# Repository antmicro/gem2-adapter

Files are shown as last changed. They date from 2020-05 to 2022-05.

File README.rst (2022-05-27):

GEM2 Adapter
============

Copyright (c) 2020 `Antmicro <https://www.antmicro.com>`_


   
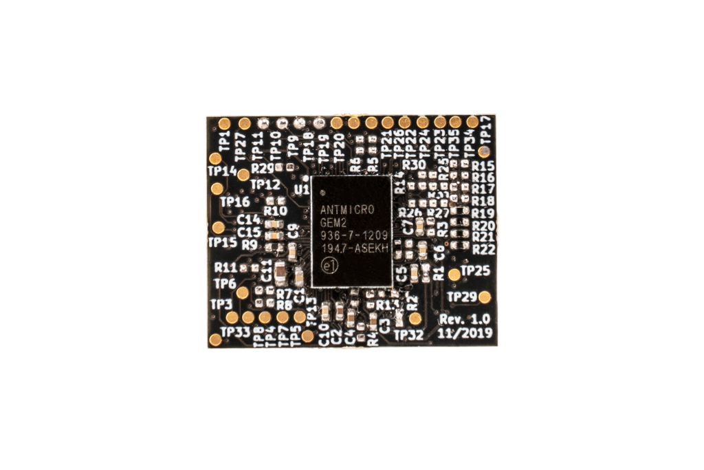
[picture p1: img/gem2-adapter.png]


This repository contains PCB design files for an adapter board accommodating the GEM2 chip created jointly by `zGlue <http://zglue.com>`_ and `Antmicro <http://www.antmicro.com>`_.
The `GEM2 design <https://zglue.com/design-automation/oci/project/gem2>`_ utilizes the zGlue ZiP chiplet technology and has been prepared using zGlue's `ChipBuilder <http://chipbuilder.zglue.com/>`_ tool.
The design has been produced as a single integrated circuit in the LGA-96 package.

The GEM2 chip contains the following components located on a dynamically reconfigurable interposer:

* PicoRV32-based "Raven" RISC-V ASIC implementation (see `raven-picorv32 <https://github.com/efabless/raven-picorv32>`_ and associated resources)
* Lattice ``ICE40UP5K-UWG30ITR`` FPGA image processing
* 32Mbit SPI FLASH memory
* 12MHz system clock generator 
* Internal LDOs and power management unit maintaining 1V2, 1V8, 2V5, 3V3 system supplies

The chip is supplied from a single ``VUSB`` voltage of 5 VDC.
The board break-routes signals for MIPI Interfaces (Input and Output) along with Flash and FPGA programming pins and power supplies.

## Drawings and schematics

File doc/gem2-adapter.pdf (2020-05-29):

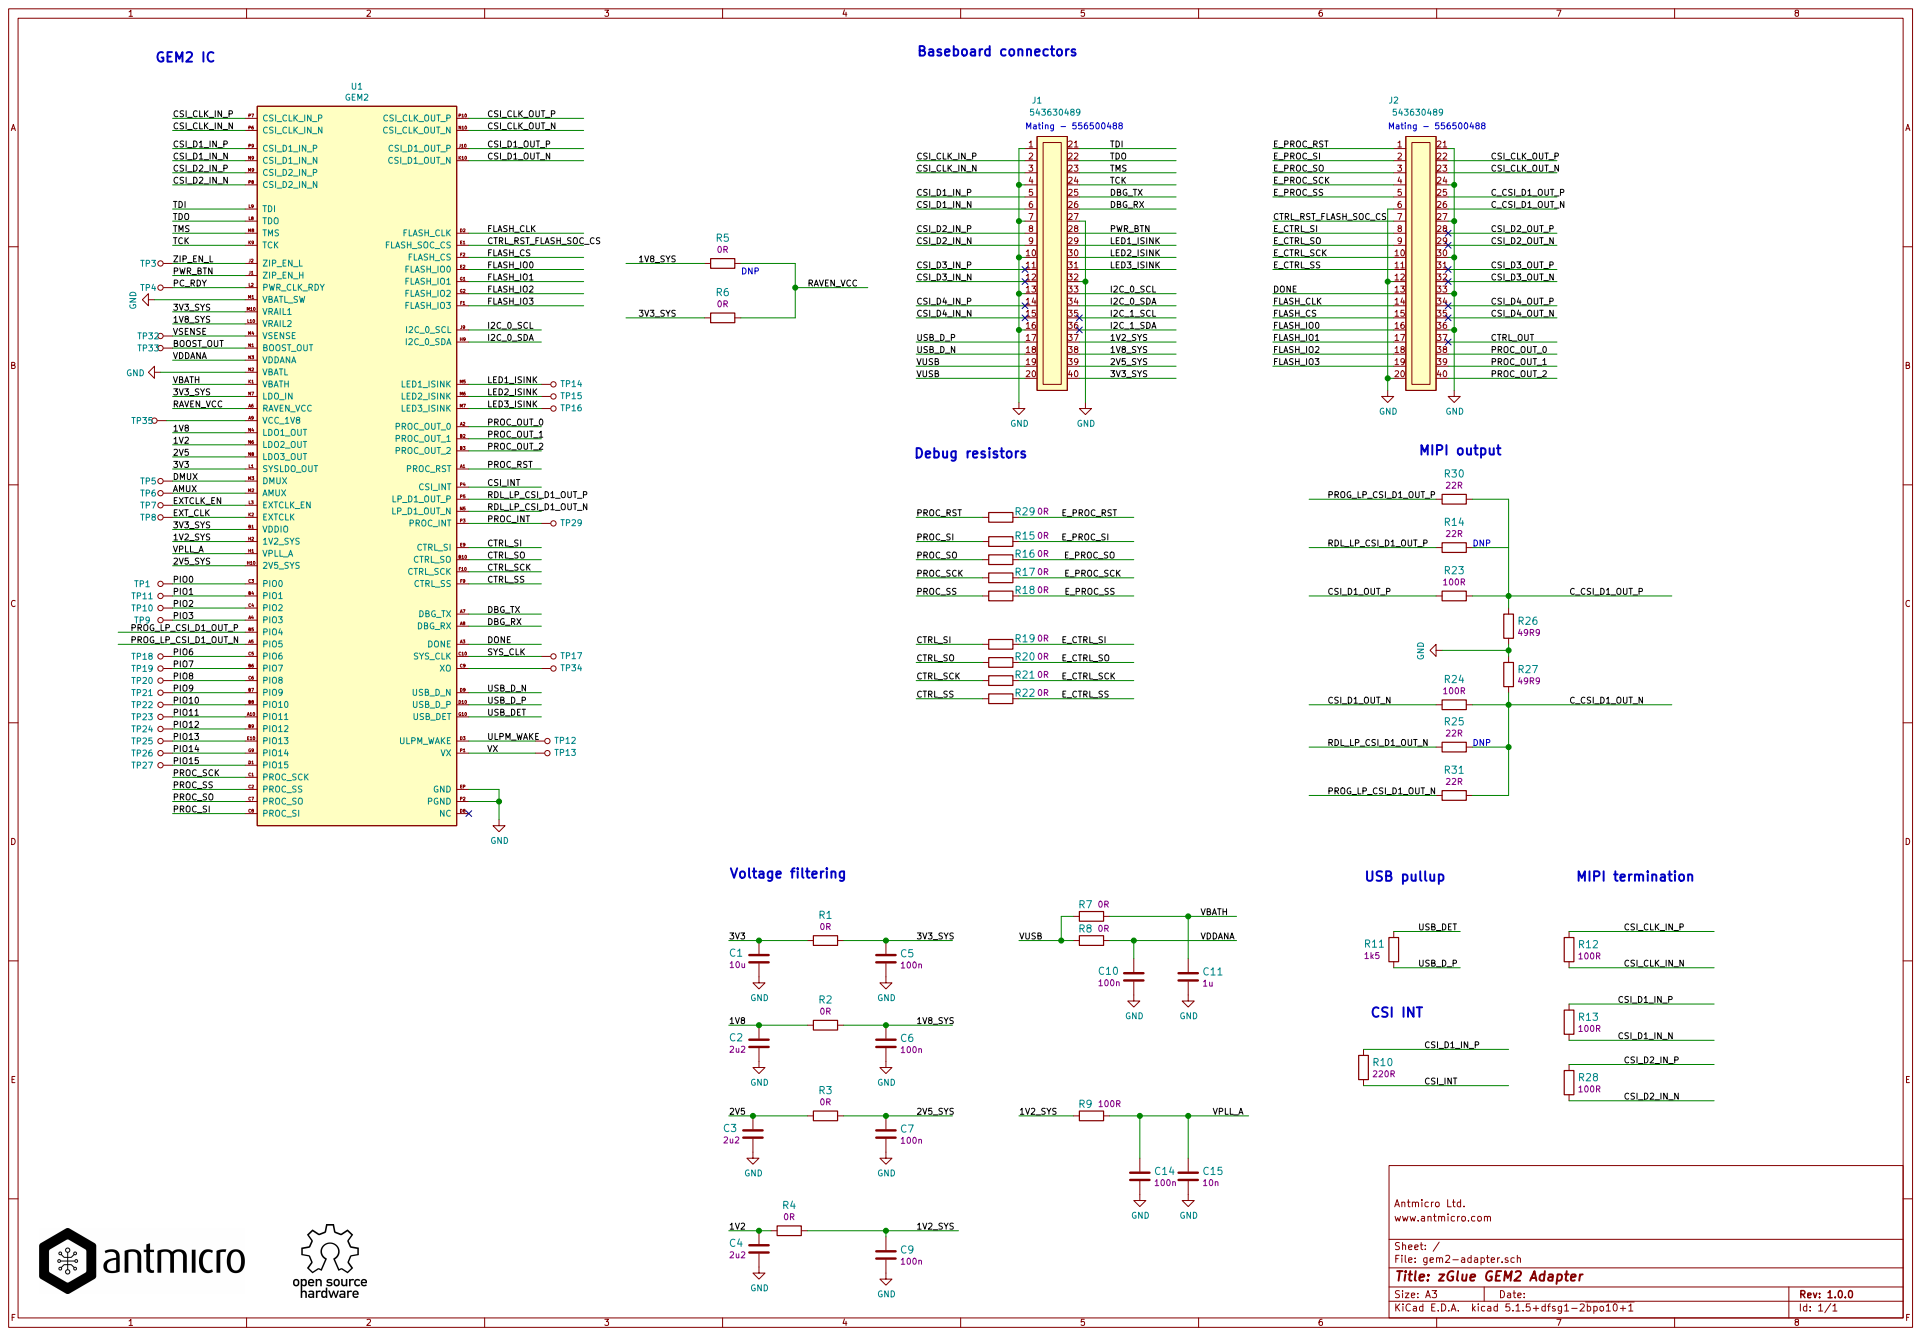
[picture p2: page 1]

Antmicro Ltd.
File: gem2-adapter.sch Sheet: / www.antmicro.com

Id: 1/1 Title: zGlue GEM2 Adapter

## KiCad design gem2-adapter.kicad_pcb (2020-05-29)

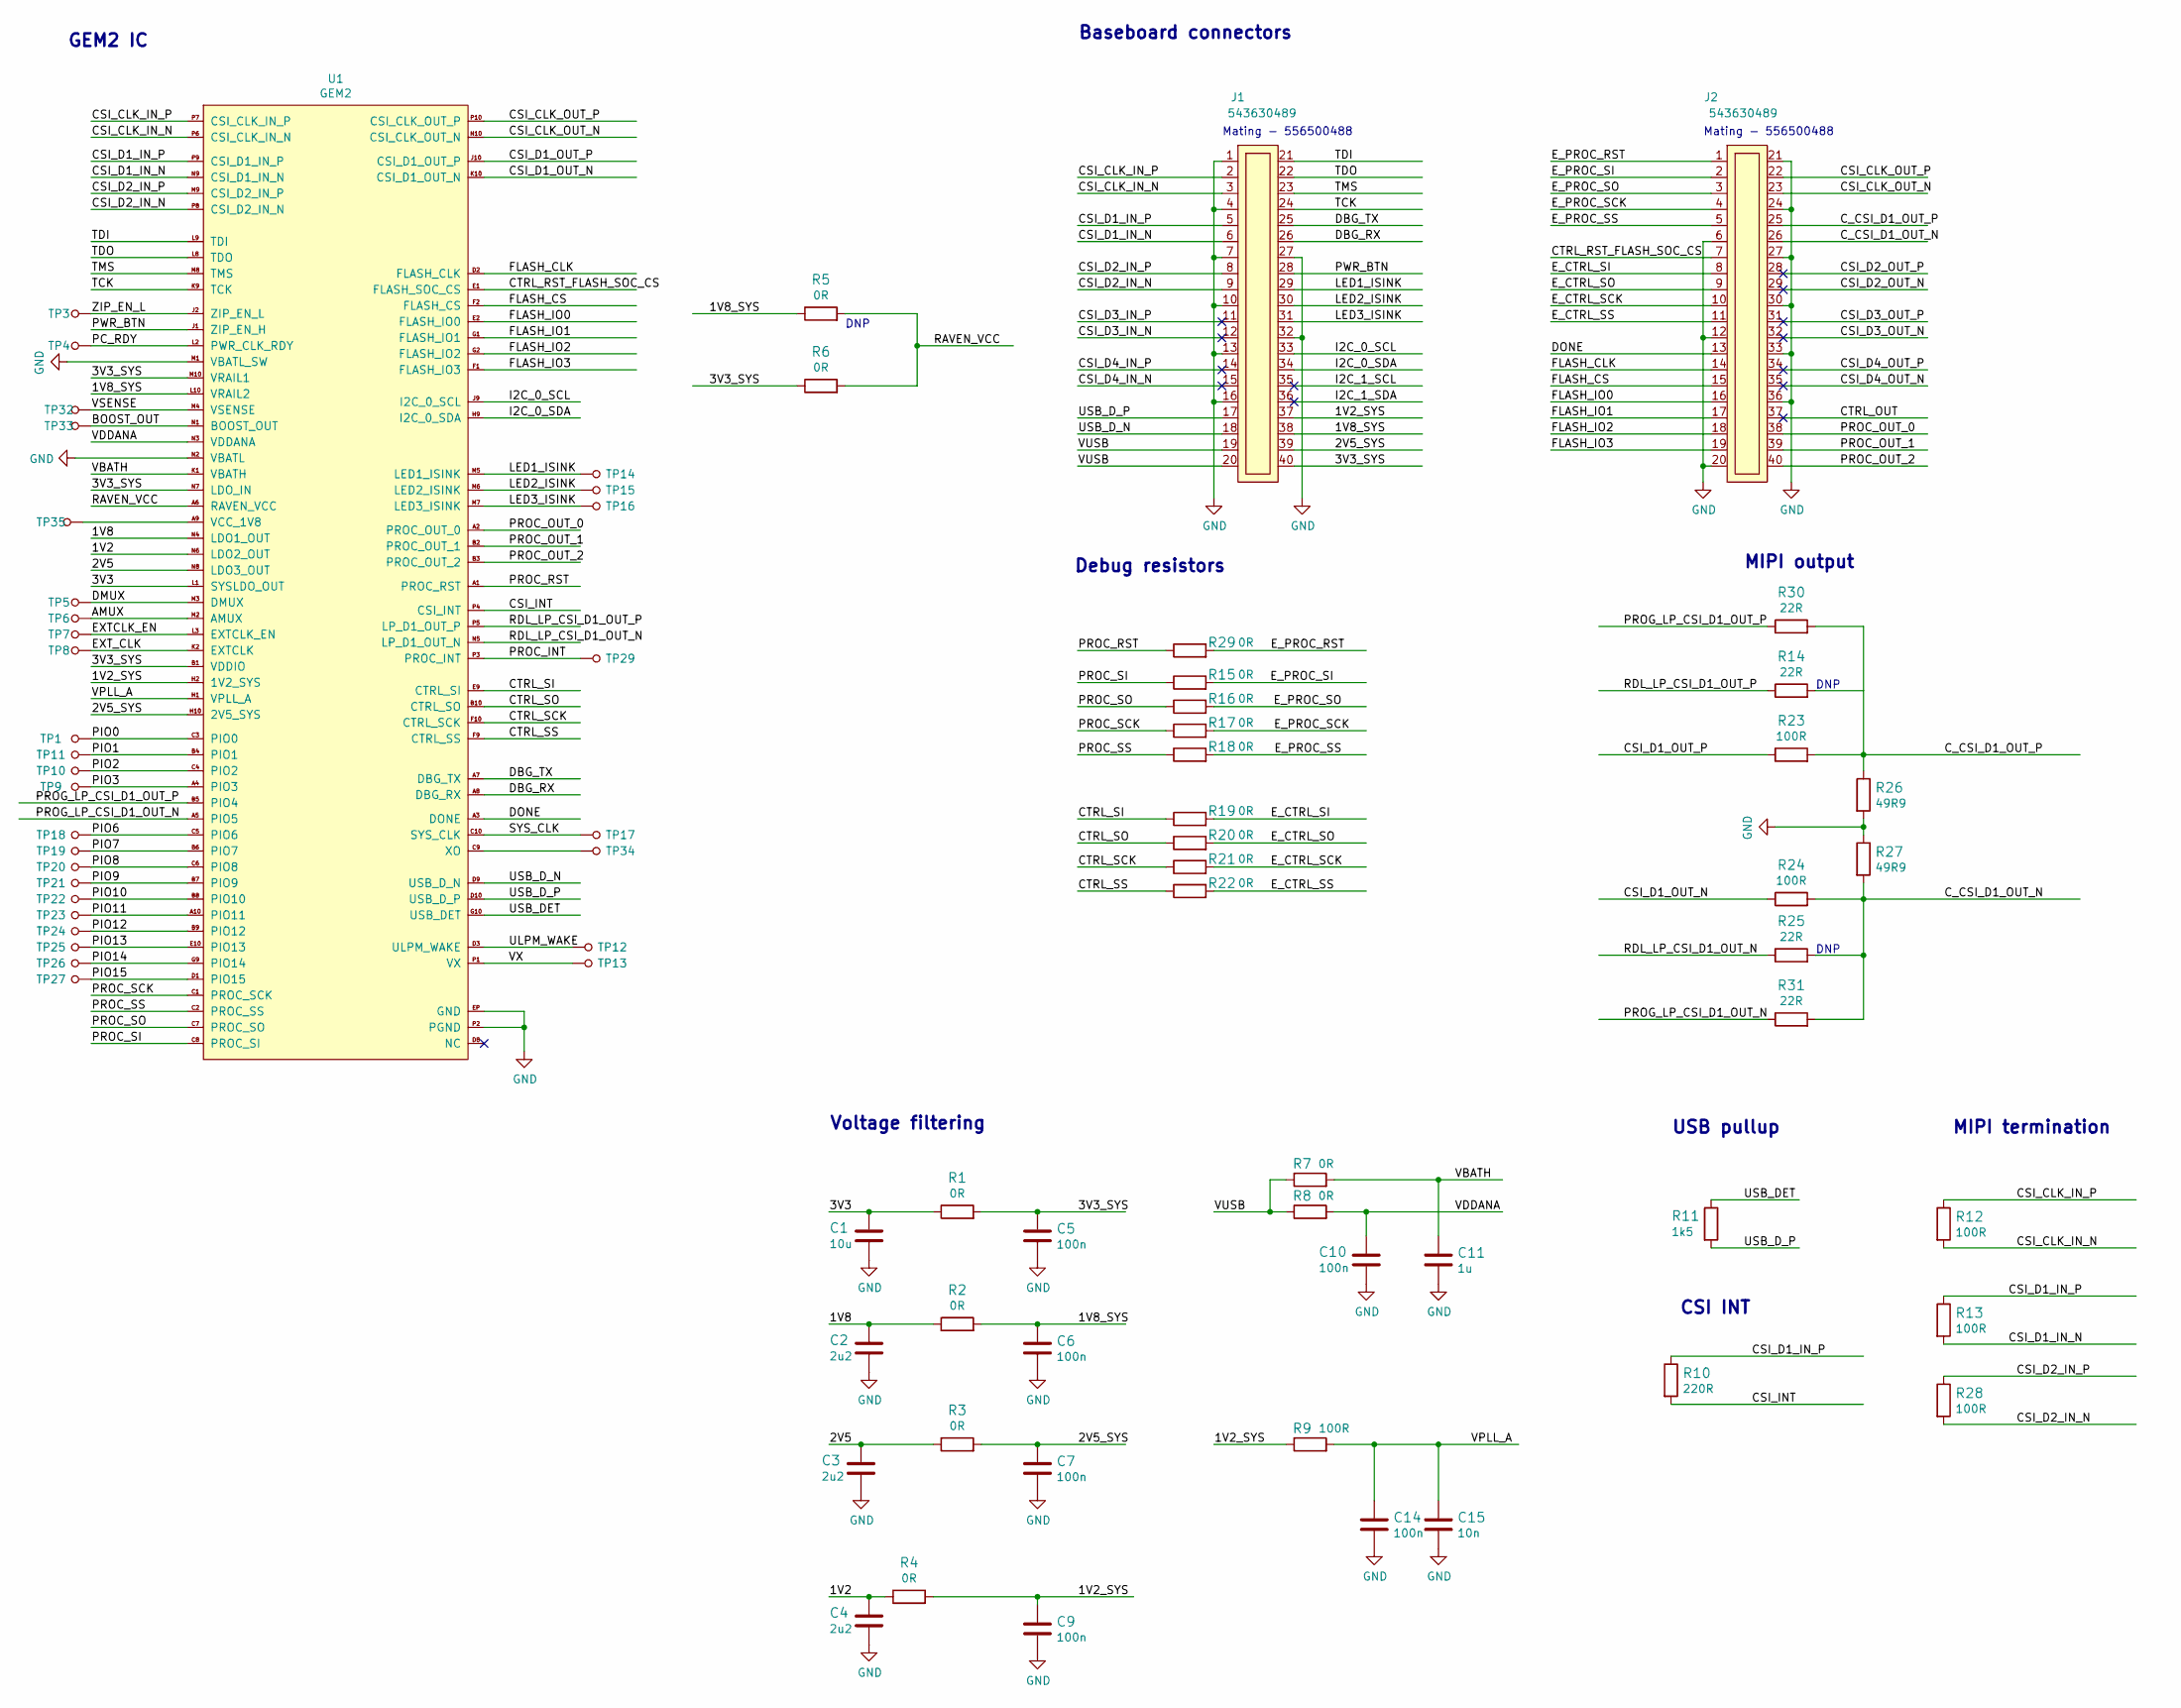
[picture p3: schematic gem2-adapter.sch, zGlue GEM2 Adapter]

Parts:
C1: C_10u_0402; 0402-cap; MPN C1005X5R0J106M050BC
C2, C3, C4: C_2u2_0402; 0402-cap; MPN C1005X5R1A225K050BC
C5, C6, C7, C9, C10, C14: C_100n_0402_6V3; 0402-cap; MPN 0402X104K6R3CT
C11: C_1u_0603; 0603-cap; MPN 0603X105K160CT
C15: C_10n_0402; 0402-cap; MPN 04025G103ZAT2A
J1, J2: 543630489; MPN 543630489
R1, R2, R3, R4, R5, R6, R7, R8, R15, R16, R17, R18, R19, R20, R21, R22, R29: R_0R_0402; 0402-res; MPN ERJ2GE0R00X
R9, R12, R13, R28: R_100R_0402; 0402-res; MPN CR0402-FX-1000GLF
R10: R_220R_0402; 0402-res; MPN CRG0402J220R
R11: R_1k5_0402; 0402-res; MPN ERJ2RKF1501X
R14, R25, R30, R31: R_22R_0402; 0402-res; MPN CRCW040222R0FKED
R23, R24: R_120R_0402; 0402-res; MPN CR0402-FX-1000GLF
R26, R27: R_49R9_0402; 0402-res; MPN CRCW040249R9FKED
TP1, TP3, TP4, TP5, TP6, TP7, TP8, TP9, TP10, TP11, TP12, TP13, TP14, TP15, TP16, TP17, TP18, TP19, TP20, TP21, TP22, TP23, TP24, TP25, TP26, TP27, TP29, TP32, TP33, TP34, TP35: TP_SMD1MM; Testpoint_smd_1mm
U1: GEM2; Z-Glue_LGA-96

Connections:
/1V2: C4.1, R4.1, U1.N6 (LDO2_OUT)
/1V2_SYS: C9.1, J1.37, R4.2, R9.1, U1.H2 (1V2_SYS)
/1V8: C2.1, R2.1, U1.N4 (LDO1_OUT)
/1V8_SYS: C6.1, J1.38, R2.2, R5.1, U1.L10 (VRAIL2)
/2V5: C3.1, R3.1, U1.N8 (LDO3_OUT)
/2V5_SYS: C7.1, J1.39, R3.2, U1.H10 (2V5_SYS)
/3V3: C1.1, R1.1, U1.L1 (SYSLDO_OUT)
/3V3_SYS: C5.1, J1.40, R1.2, R6.1, U1.B1 (VDDIO), U1.M10 (VRAIL1), U1.N7 (LDO_IN)
/AMUX: TP6.1, U1.M2 (AMUX)
/BOOST_OUT: TP33.1, U1.N1 (BOOST_OUT)
/CSI_CLK_IN_N: J1.3, R12.2, U1.P6 (CSI_CLK_IN_N)
/CSI_CLK_IN_P: J1.2, R12.1, U1.P7 (CSI_CLK_IN_P)
/CSI_CLK_OUT_N: J2.23, U1.N10 (CSI_CLK_OUT_N)
/CSI_CLK_OUT_P: J2.22, U1.P10 (CSI_CLK_OUT_P)
/CSI_D1_IN_N: J1.6, R13.2, U1.N9 (CSI_D1_IN_N)
/CSI_D1_IN_P: J1.5, R10.1, R13.1, U1.P9 (CSI_D1_IN_P)
/CSI_D1_OUT_N: R24.1, U1.K10 (CSI_D1_OUT_N)
/CSI_D1_OUT_P: R23.1, U1.J10 (CSI_D1_OUT_P)
/CSI_D2_IN_N: J1.9, R28.2, U1.P8 (CSI_D2_IN_N)
/CSI_D2_IN_P: J1.8, R28.1, U1.M9 (CSI_D2_IN_P)
/CSI_D2_OUT_N: J2.29
/CSI_D2_OUT_P: J2.28
/CSI_D3_IN_N: J1.12
/CSI_D3_IN_P: J1.11
/CSI_D3_OUT_N: J2.32
/CSI_D3_OUT_P: J2.31
/CSI_D4_IN_N: J1.15
/CSI_D4_IN_P: J1.14
/CSI_D4_OUT_N: J2.35
/CSI_D4_OUT_P: J2.34
/CSI_INT: R10.2, U1.P4 (CSI_INT)
/CTRL_OUT: J2.37
/CTRL_RST_FLASH_SOC_CS: J2.7, U1.E1 (FLASH_SOC_CS)
/CTRL_SCK: R21.1, U1.F10 (CTRL_SCK)
/CTRL_SI: R19.1, U1.E9 (CTRL_SI)
/CTRL_SO: R20.1, U1.B10 (CTRL_SO)
/CTRL_SS: R22.1, U1.F9 (CTRL_SS)
/C_CSI_D1_OUT_N: J2.26, R24.2, R25.2, R27.2, R31.2
/C_CSI_D1_OUT_P: J2.25, R14.2, R23.2, R26.1, R30.2
/DBG_RX: J1.26, U1.A8 (DBG_RX)
/DBG_TX: J1.25, U1.A7 (DBG_TX)
/DMUX: TP5.1, U1.M3 (DMUX)
/DONE: J2.13, U1.A3 (DONE)
/EXTCLK_EN: TP7.1, U1.L3 (EXTCLK_EN)
/EXT_CLK: TP8.1, U1.K2 (EXTCLK)
/E_CTRL_SCK: J2.10, R21.2
/E_CTRL_SI: J2.8, R19.2
/E_CTRL_SO: J2.9, R20.2
/E_CTRL_SS: J2.11, R22.2
/E_PROC_RST: J2.1, R29.2
/E_PROC_SCK: J2.4, R17.2
/E_PROC_SI: J2.2, R15.2
/E_PROC_SO: J2.3, R16.2
/E_PROC_SS: J2.5, R18.2
/FLASH_CLK: J2.14, U1.D2 (FLASH_CLK)
/FLASH_CS: J2.15, U1.F2 (FLASH_CS)
/FLASH_IO0: J2.16, U1.E2 (FLASH_IO0)
/FLASH_IO1: J2.17, U1.G1 (FLASH_IO1)
/FLASH_IO2: J2.18, U1.G2 (FLASH_IO2)
/FLASH_IO3: J2.19, U1.F1 (FLASH_IO3)
/I2C_0_SCL: J1.33, U1.J9 (I2C_0_SCL)
/I2C_0_SDA: J1.34, U1.H9 (I2C_0_SDA)
/I2C_1_SCL: J1.35
/I2C_1_SDA: J1.36
/LED1_ISINK: J1.29, TP14.1, U1.M5 (LED1_ISINK)
/LED2_ISINK: J1.30, TP15.1, U1.M6 (LED2_ISINK)
/LED3_ISINK: J1.31, TP16.1, U1.M7 (LED3_ISINK)
/PC_RDY: TP4.1, U1.L2 (PWR_CLK_RDY)
/PIO0: TP1.1, U1.C3 (PIO0)
/PIO1: TP11.1, U1.B4 (PIO1)
/PIO2: TP10.1, U1.C4 (PIO2)
/PIO3: TP9.1, U1.A4 (PIO3)
/PIO6: TP18.1, U1.C5 (PIO6)
/PIO7: TP19.1, U1.B6 (PIO7)
/PIO8: TP20.1, U1.C6 (PIO8)
/PIO9: TP21.1, U1.B7 (PIO9)
/PIO10: TP22.1, U1.B8 (PIO10)
/PIO11: TP23.1, U1.A10 (PIO11)
/PIO12: TP24.1, U1.B9 (PIO12)
/PIO13: TP25.1, U1.E10 (PIO13)
/PIO14: TP26.1, U1.G9 (PIO14)
/PIO15: TP27.1, U1.D1 (PIO15)
/PROC_INT: TP29.1, U1.P3 (PROC_INT)
/PROC_OUT_0: J2.38, U1.A2 (PROC_OUT_0)
/PROC_OUT_1: J2.39, U1.B2 (PROC_OUT_1)
/PROC_OUT_2: J2.40, U1.B3 (PROC_OUT_2)
/PROC_RST: R29.1, U1.A1 (PROC_RST)
/PROC_SCK: R17.1, U1.C1 (PROC_SCK)
/PROC_SI: R15.1, U1.C8 (PROC_SI)
/PROC_SO: R16.1, U1.C7 (PROC_SO)
/PROC_SS: R18.1, U1.C2 (PROC_SS)
/PROG_LP_CSI_D1_OUT_N: R31.1, U1.A5 (PIO5)
/PROG_LP_CSI_D1_OUT_P: R30.1, U1.B5 (PIO4)
/PWR_BTN: J1.28, U1.J1 (ZIP_EN_H)
/RAVEN_VCC: R5.2, R6.2, U1.A6 (RAVEN_VCC)
/RDL_LP_CSI_D1_OUT_N: R25.1, U1.N5 (LP_D1_OUT_N)
/RDL_LP_CSI_D1_OUT_P: R14.1, U1.P5 (LP_D1_OUT_P)
/SYS_CLK: TP17.1, U1.C10 (SYS_CLK)
/TCK: J1.24, U1.K9 (TCK)
/TDI: J1.21, U1.L9 (TDI)
/TDO: J1.22, U1.L8 (TDO)
/TMS: J1.23, U1.M8 (TMS)
/ULPM_WAKE: TP12.1, U1.D3 (ULPM_WAKE)
/USB_DET: R11.1, U1.G10 (USB_DET)
/USB_D_N: J1.18, U1.D9 (USB_D_N)
/USB_D_P: J1.17, R11.2, U1.D10 (USB_D_P)
/VBATH: C11.1, R7.2, U1.K1 (VBATH)
/VDDANA: C10.1, R8.2, U1.N3 (VDDANA)
/VPLL_A: C14.1, C15.1, R9.2, U1.H1 (VPLL_A)
/VSENSE: TP32.1, U1.M4 (VSENSE)
/VUSB: J1.19, J1.20, R7.1, R8.1
/VX: TP13.1, U1.P1 (VX)
/ZIP_EN_L: TP3.1, U1.J2 (ZIP_EN_L)
GND: C1.2, C2.2, C3.2, C4.2, C5.2, C6.2, C7.2, C9.2, C10.2, C11.2, C14.2, C15.2, J1.1, J1.4, J1.7, J1.10, J1.13, J1.16, J1.27, J1.32, J2.6, J2.12, J2.20, J2.21, J2.24, J2.27, J2.30, J2.33, J2.36, R26.2, R27.1, U1.EP (GND), U1.M1 (VBATL_SW), U1.N2 (VBATL), U1.P2 (PGND)
unnamed: TP34.1, U1.C9 (XO)
unnamed: TP35.1, U1.A9 (VCC_1V8)

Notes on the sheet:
GEM2 IC
Voltage filtering
Mating - 556500488
Baseboard connectors
Debug resistors
USB pullup
MIPI termination
CSI INT
MIPI output
DNP

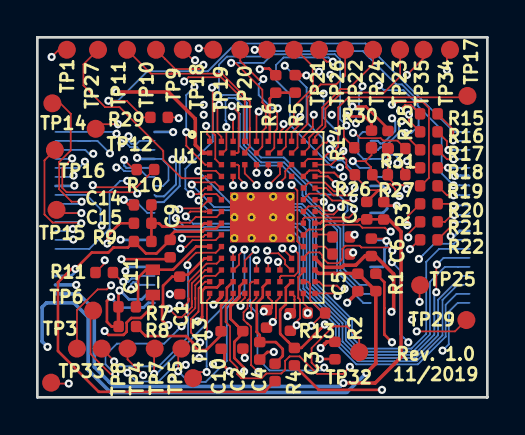
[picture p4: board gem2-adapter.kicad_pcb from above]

Board: 6 copper layers, 25.0 x 20.0 mm, 77 parts (0 on the bottom side), 103 nets.

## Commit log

2020-05-29 Add component placement
    [zglue-jade-adapter.sch]
2020-05-29 Add LGA-96 step model, fix library links
    [zglue-jade-adapter-B.CrtYd.gbr, zglue-jade-adapter-B.Mask.gbr, zglue-jade-adapter-B.Paste.gbr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]
2020-05-29 Rotate PCB by 180 deg to match chip logo orientation
    [zglue-jade-adapter-B.CrtYd.gbr, zglue-jade-adapter-B.Mask.gbr, zglue-jade-adapter-B.Paste.gbr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]
2020-05-29 Move C1,2,3,4 closer to LDOs' outputs
    [zglue-jade-adapter.sch]
2020-05-29 Modify LGA-96 thermal pad on paste layer
    [zglue-jade-adapter.kicad_pcb]
2020-05-29 Add initial layout
    [zglue-jade-adapter-B.CrtYd.gbr, zglue-jade-adapter-B.Mask.gbr, zglue-jade-adapter-B.Paste.gbr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]
2020-05-29 Tune differential pairs
    [zglue-jade-adapter-B.CrtYd.gbr, zglue-jade-adapter-B.Mask.gbr, zglue-jade-adapter-B.Paste.gbr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]
2020-05-29 Minor tweaks
    [zglue-jade-adapter-B.CrtYd.gbr, zglue-jade-adapter-B.Mask.gbr, zglue-jade-adapter-B.Paste.gbr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]
2020-05-29 Add 3D Vis to README
    [zglue-jade-adapter.sch]
2020-05-29 Add CSI_LP and CSI_INT signals and corresponding resistors
    [zglue-jade-adapter-B.CrtYd.gbr, zglue-jade-adapter-B.Mask.gbr, zglue-jade-adapter-B.Paste.gbr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]
2020-05-29 Add DNP annotations
    [zglue-jade-adapter.sch]
2020-05-29 Update pinout and layout
    [zglue-jade-adapter-B.CrtYd.gbr, zglue-jade-adapter-B.Mask.gbr, zglue-jade-adapter-B.Paste.gbr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]
2020-05-29 Update the grid origin
    [zglue-jade-adapter-B.CrtYd.gbr, zglue-jade-adapter-B.Mask.gbr, zglue-jade-adapter-B.Paste.gbr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]
2020-05-29 Add resistors for choosing CSI_LP signals connection
    [zglue-jade-adapter-B.CrtYd.gbr, zglue-jade-adapter-B.Mask.gbr, zglue-jade-adapter-B.Paste.gbr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]
2020-05-29 Regenerate libraries
    [zglue-jade-adapter.kicad_pcb, zglue-jade-adapter.sch]
2020-05-29 README updates
    [zglue-gem2-adapter.kicad_pcb, zglue-gem2-adapter.sch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]
2020-05-29 Update GEM2 symbol
    [zglue-gem2-adapter.sch]
2020-05-29 Make more space on schematic sheet
    [zglue-gem2-adapter.sch]
2020-05-29 Update PCB
    [zglue-gem2-adapter.kicad_pcb]
2020-05-29 Update library naming
    [gem2-adapter.kicad_pcb, gem2-adapter.sch]
2020-05-29 Add logotype
    [gem2-adapter.sch]
2020-05-29 Update PDF schematic
